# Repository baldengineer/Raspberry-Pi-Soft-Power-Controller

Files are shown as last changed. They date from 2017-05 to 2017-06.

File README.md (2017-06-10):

# Raspberry-Pi-Soft-Power-Controller

For now, you can find more information at:
https://hackaday.io/project/21625-raspberry-pi-soft-power-controller

## Requirements
* Raspberry Pi running Jessie
* 2 GPIO Pins on Raspberry Pi
* AVR (Arduino Uno, Leonardo, etc) w/ 2 GPIO
* Slide Switch (or Pushbutton)

### Optional
* Bald Engineer's RetroPie Controller

## Notes
* Currently the AVR code is designed for a SPST switch and not a push button. I'm working on a push button version, but that isn't what I needed in my project. 
* Please don't fab the PCBs as-is. There are design issues for them. I am open to collaboration on a "hat" version of these boards. I have some ideas. (Key, can we mount a barrel jack upside down??)

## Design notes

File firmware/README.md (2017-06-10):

# firmware

There are two pieces to this project. The code that runs on the AVR (power controller) and some code that runs on the Pi itself. The code on the AVR is somewhat generic, so it could probably power Beagle Bone or other Single-Board Computers.

The code for the RaspberryPi is compiled C code, not python. (You could use Python, but I didn't.) It makes use of the wiringPi library. NOOBS Jessie from April 2017 includes a version of that library in the stock install.

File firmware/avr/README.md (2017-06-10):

# AVR Code

The project I developed this controller for is based on a Arduino Leonardo. That board uses a 32u4 AVR chip. The code itself should be compatible with the 328p and 2560 based boards. However, you will need to change up the I/O pins. (I'm using a custom board.)

Commit b4071b1ddd632b1c1035af2f0c8c23c28ab442d6 was a complete re-write of the original code. As of that commit, it is still a bit messy. However, it works. :)

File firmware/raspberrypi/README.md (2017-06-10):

# RaspberryPi Code
There are two types of files in this directory. One is C-based programs. The other is systemd services. You need them all installed. Here's some detailed notes.

## C-Programs
This project doesn't use Python, it uses C. So you'll need to compile the code on your Pi. These utlities require the "[Wiring Pi](http://wiringpi.com/)" library installed. 

### Installing Wiring Pi
My copy of Jessie had Wiring Pi installed. You can tell by running this command:
```
$ gpio -v
```
If you get something back, it is installed. If you'd like the latest version (or you don't have it installed at all) follow these directions on [installing the latest wiringPi](http://wiringpi.com/download-and-install/).

### C-Start.c
This utility runs at startup. It enables a specific GPIO pin as output and sets it HIGH. I'm using GPIO18 (which is pin 1 in WiringPi's numbering convention. See below for details.) It only needs user-level privilege. 

Compile this code and "install" using:
```
$ gcc c-start.c -o c-start -lwiringPi
$ cp c-start /usr/local/bin/
```
### C-Stop.c
This utility runs during shutdown (and reboot.) It enables a specific GPIO pin as output and sets it LOW. I'm using GPIO18 (which is pin 1 in WiringPi's numbering convention. See below for details.) It only needs user-level privilege. 

Compile this code and "install" using:
```
$ gcc c-stop.c -o c-stop -lwiringPi
$ cp c-stop /usr/local/bin/
```

## systemd services
A big difference between "wheezy" and "jessie" is the init process. wheezy uses SystemInitV and jessie uses systemd. I found a *ton* of questions on how to run a script on startup or shutdown on the raspberry Pi. Everything was SystemInitV based, which won't work with the latest versions of Raspbian. (e.g. if you find putting things in /etc/rc.d isn't working, your linux is probably using systemd).

These could probably be combined into the same service, but I didn't try yet. Also, I can't figure out how to get the shutdown signal to work only on shutdown (and not reboot.)

### powercontrol-comms.service
This service will run c-start during boot and c-stop during shutdown. This is the signal our AVR-based power controller is monitoring. To install, put this file into `/etc/systemd/system`. (Note /lib/systemd is meant for *system* files. Not *user* files.) Once copied, do this:

```
$ cd /etc/systemd/system
$ ls powercontrol-coms.service #verify it is there
$ sudo systemctl enable powercontrol-coms.service
# reboot (or install the next one)
```
Make sure you copy `c-start` and `c-stop` to `/usr/local/bin/`.

### shutdown-gpio.service
This service will run c-watch during boot. This program checks once every second whether the power controller has told us to shutdown. To install, put this file into `/etc/systemd/system`. (Note /lib/systemd is meant for *system* files. Not *user* files.) Once copied, do this:

```
$ cd /etc/systemd/system
$ ls shutdown-gpio.service #verify it is there
$ sudo systemctl enable shutdown-gpio.service
# reboot (or install the previous)
```
Make sure you copy `c-start` and `c-stop` to `/usr/local/sbin/` (different from other file).

## Wiring Pi Pin Numbers
WiringPi has it's own numbering convention. So I made this table to be a quick look up for pin numbers. You can also run "gpio readall" on the Pi for a table.
```
Special :    SD SC                   MO MI SK    | ID  
WiringPi: 3v 08 09 07 0v 00 02 03 3v 12 13 14 0v | 00 05 06 13 19 26 0v
Physical: 01 03 05 07 09 11 13 15 17 19 21 23 25 | 27 29 31 33 35 37 39

Special :          TX RX                   C0 C1 | IC
WiringPi: 5v 5v 0v 15 16 01 0v 04 05 0v 06 10 11 | 01 0v 12 0v 16 20 21
Physical: 02 04 06 08 10 12 14 16 18 20 22 24 26 | 28 30 32 34 36 38 40
```

Special are special functions, so you probably don't want to use those for the power controller. Physical are the actual pin numbers. And then WiringPi is the number to use in the C-code to correspond with the Physical pin number. (It's confusing, but that's why I made the chart.)

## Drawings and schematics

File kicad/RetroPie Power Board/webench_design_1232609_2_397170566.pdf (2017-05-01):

## WEBENCH ® Design Report

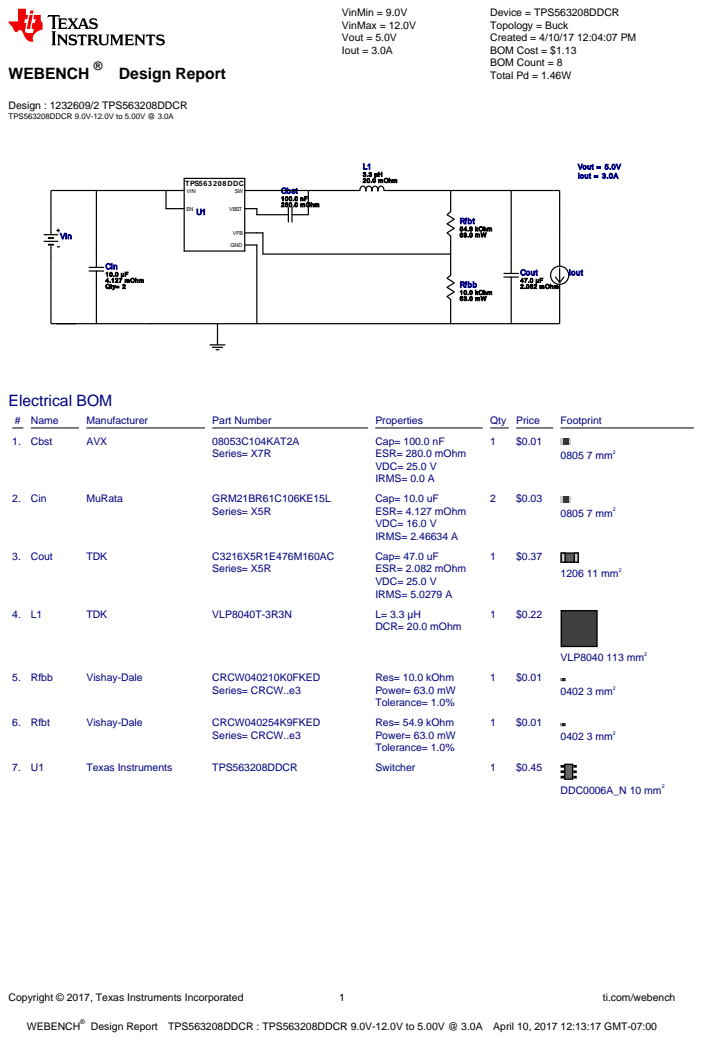
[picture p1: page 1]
Copyright © 2017, Texas Instruments Incorporated; ti.com/webench; WEBENCH®; Design : 1232609/2 TPS563208DDCR TPS563208DDCR 9.0V-12.0V to 5.00V @ 3.0A; VinMin = 9.0V VinMax = 12.0V Vout = 5.0V Iout = 3.0A; Device = TPS563208DDCR Topology = Buck Created = 4/10/17 12:04:07 PM BOM Cost = $1.13 BOM Count = 8 Total Pd = 1.46W; Cbst 100.0 nF 280.0 mOhm; Cin 10.0 µF 4.127 mOhm Qty= 2; Cout 47.0 µF 2.082 mOhm; L1 3.3 µH 20.0 mOhm; Rfbb 10.0 kOhm 63.0 mW; TPS563208DDC; GND; VIN; VFB; VBST U1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

Design Report TPS563208DDCR : TPS563208DDCR 9.0V-12.0V to 5.00V @ 3.0A April 10, 2017 12:13:17 GMT-07:00

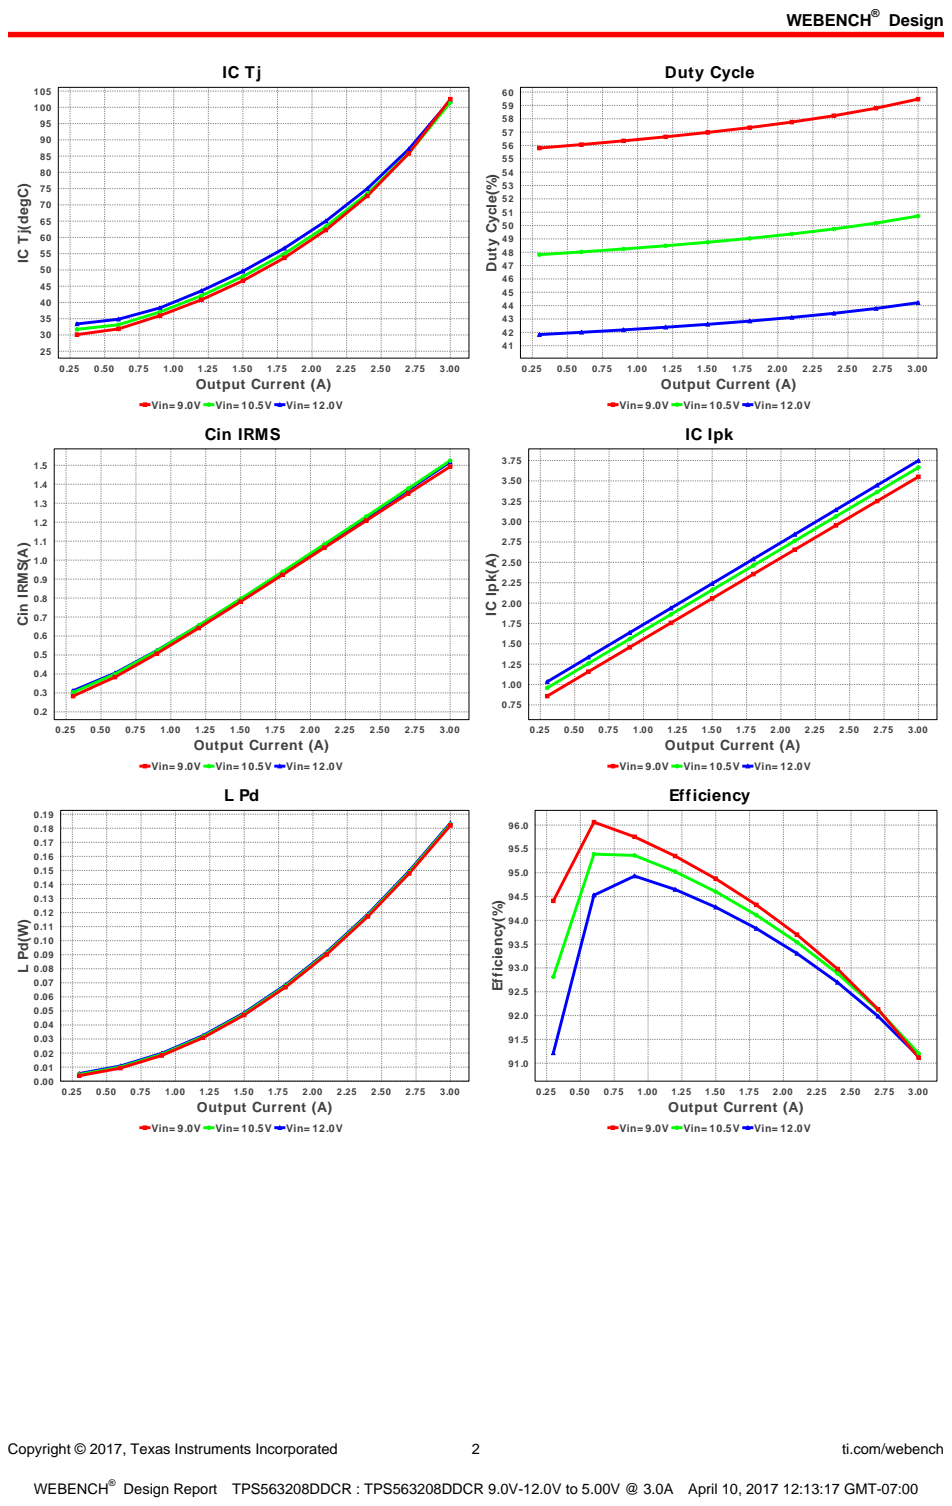
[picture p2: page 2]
Design; Copyright © 2017, Texas Instruments Incorporated; ti.com/webench; 3.00 Output Current (A); Duty Cycle; Duty Cycle(%); Cin IRMS(A); IC Ipk; IC Ipk(A); Efficiency(%)

IC Tj(degC)

Vin= 9.0V Vin= 10.5V Vin= 12.0V
Cin IRMS

Efficiency

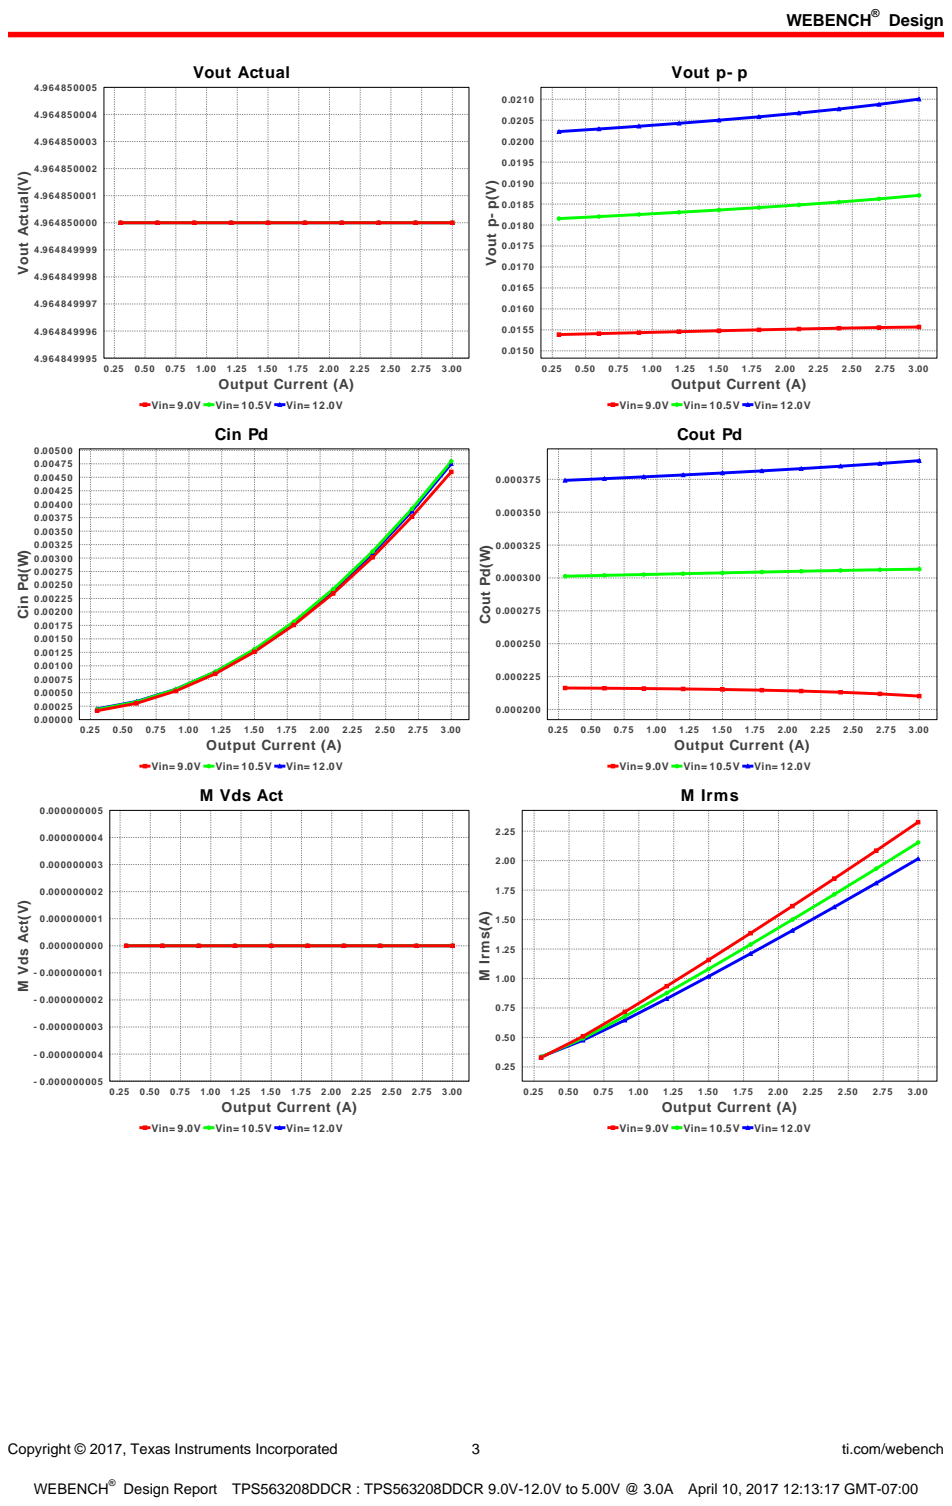
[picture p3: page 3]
Copyright © 2017, Texas Instruments Incorporated; ti.com/webench; Vout Actual; 0.25 0.50 0.75 1.00 1.25 1.50 1.75 2.00 2.25 2.50 2.75 3.00 Output Current (A); Vout Actual(V); Vout p- p; 3.00 Output Current (A); Vout p- p(V); Cin Pd; Cin Pd(W); Cout Pd(W); M Vds Act(V); M Irms; M Irms(A)

Vin= 9.0V Vin= 10.5V Vin= 12.0V

Cout Pd

M Vds Act

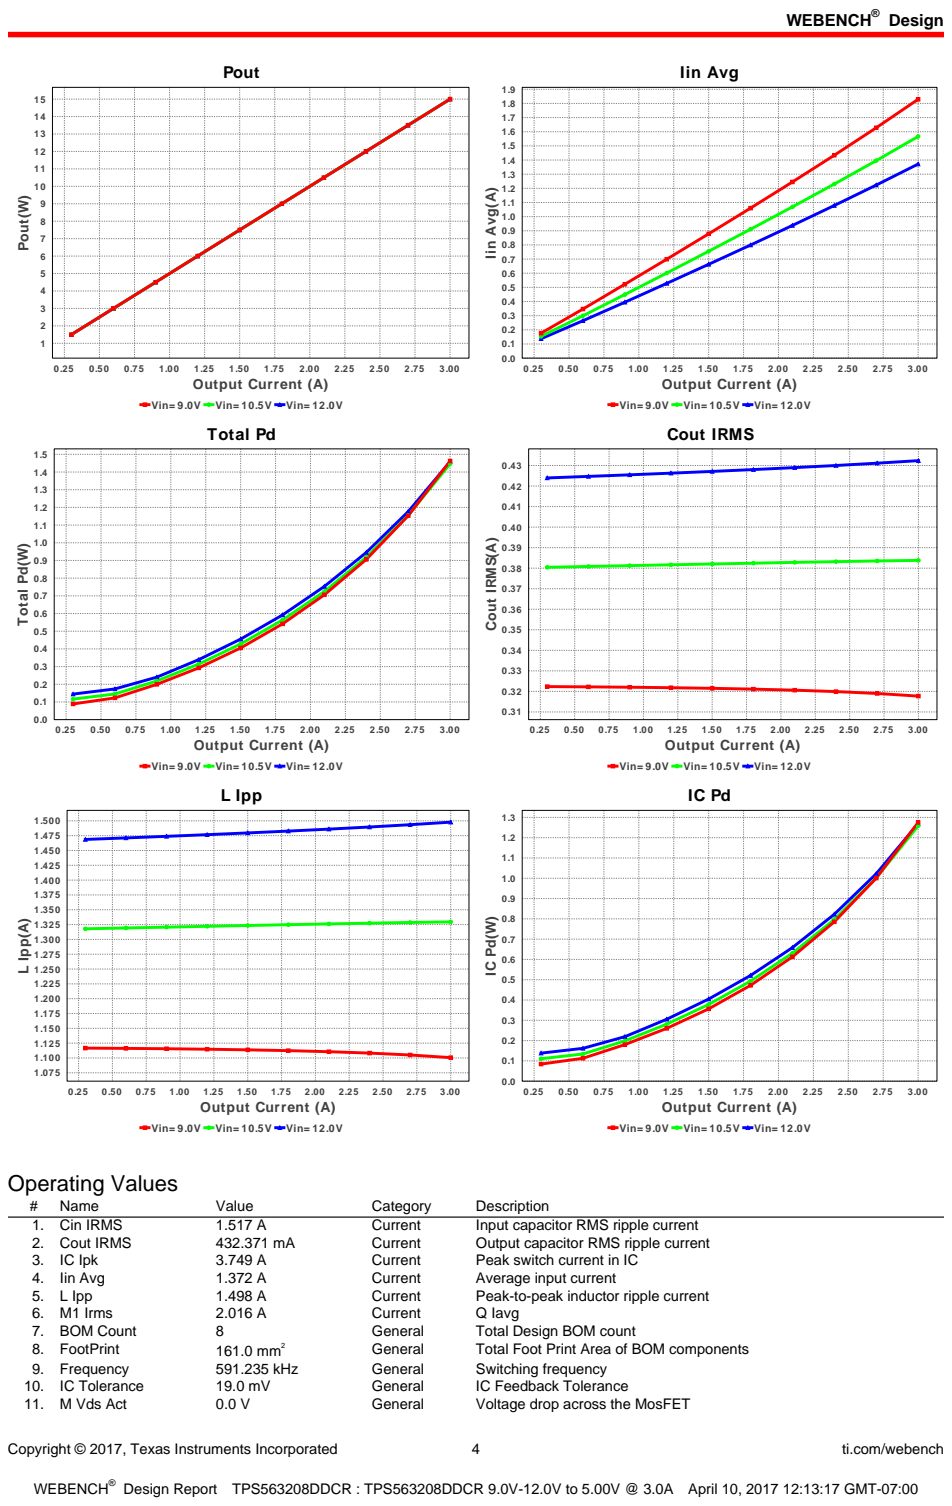
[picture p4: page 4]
Copyright © 2017, Texas Instruments Incorporated; ti.com/webench; Pout; 3.00 Output Current (A); Pout(W); Iin Avg; Iin Avg(A); Total Pd(W); Cout IRMS(A); L Ipp; L Ipp(A); Operating Values; Name; Value; Category; Description; 1. Cin IRMS; Current; Input capacitor RMS ripple current; 2. Cout IRMS; Output capacitor RMS ripple current; 3. IC Ipk; Peak switch current in IC; 4. Iin Avg; Average input current; 5. L Ipp; Peak-to-peak inductor ripple current; 6. M1 Irms; Q Iavg; 7. BOM Count; General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

Vin= 9.0V Vin= 10.5V Vin= 12.0V
Total Pd

Cout IRMS

Copyright © 2017, Texas Instruments Incorporated | 5 | ti.com/webench
# | Name | Value | Category | Description

12. Mode | CCM | General | Conduction Mode
13. Pout | 15.0 W | General | Total output power
14. Total BOM | $1.13 | General | Total BOM Cost
15. Vout Actual | 4.965 V | Op_Point | Vout Actual calculated based on selected voltage divider resistors
16. Vout OP | 5.0 V | Op_Point | Operational Output Voltage
17. Duty Cycle | 44.22 % | Op_point | Duty cycle
18. Efficiency | 91.139 % | Op_point | Steady state efficiency
19. IC Tj | 102.159 degC | Op_point | IC junction temperature
20. ICThetaJA | 60.8 degC/W | Op_point | IC junction-to-ambient thermal resistance
21. IOUT_OP | 3.0 A | Op_point | Iout operating point
22. VIN_OP | 12.0 V | Op_point | Vin operating point
23. Vout p-p | 21.003 mV | Op_point | Peak-to-peak output ripple voltage
24. Cin Pd | 4.751 mW | Power | Input capacitor power dissipation
25. Cout Pd | 389.218 µW | Power | Output capacitor power dissipation
26. IC Pd | 1.269 W | Power | IC power dissipation
27. L Pd | 183.739 mW | Power | Inductor power dissipation
28. Total Pd | 1.458 W | Power | Total Power Dissipation
29. Vout Tolerance | 4.235 % | Vout Tolerance based on IC Tolerance (no load) and voltage divider
| | | | resistors if applicable

## Design Inputs

# | Name | Value | Description

1. Iout | 3.0 | Maximum Output Current
2. VinMax | 12.0 | Maximum input voltage
3. VinMin | 9.0 | Minimum input voltage
4. Vout | 5.0 | Output Voltage
5. base_pn | TPS563208 | Base Product Number
6. source | DC | Input Source Type
7. Ta | 25.0 | Ambient temperature

## Design Assistance
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

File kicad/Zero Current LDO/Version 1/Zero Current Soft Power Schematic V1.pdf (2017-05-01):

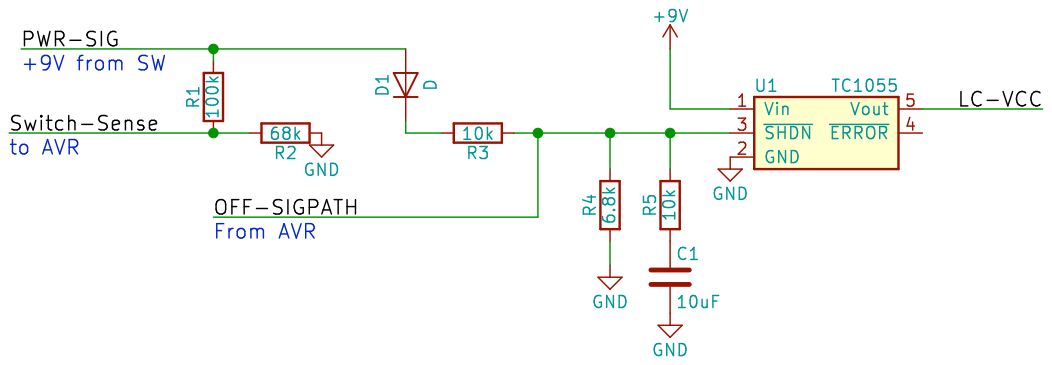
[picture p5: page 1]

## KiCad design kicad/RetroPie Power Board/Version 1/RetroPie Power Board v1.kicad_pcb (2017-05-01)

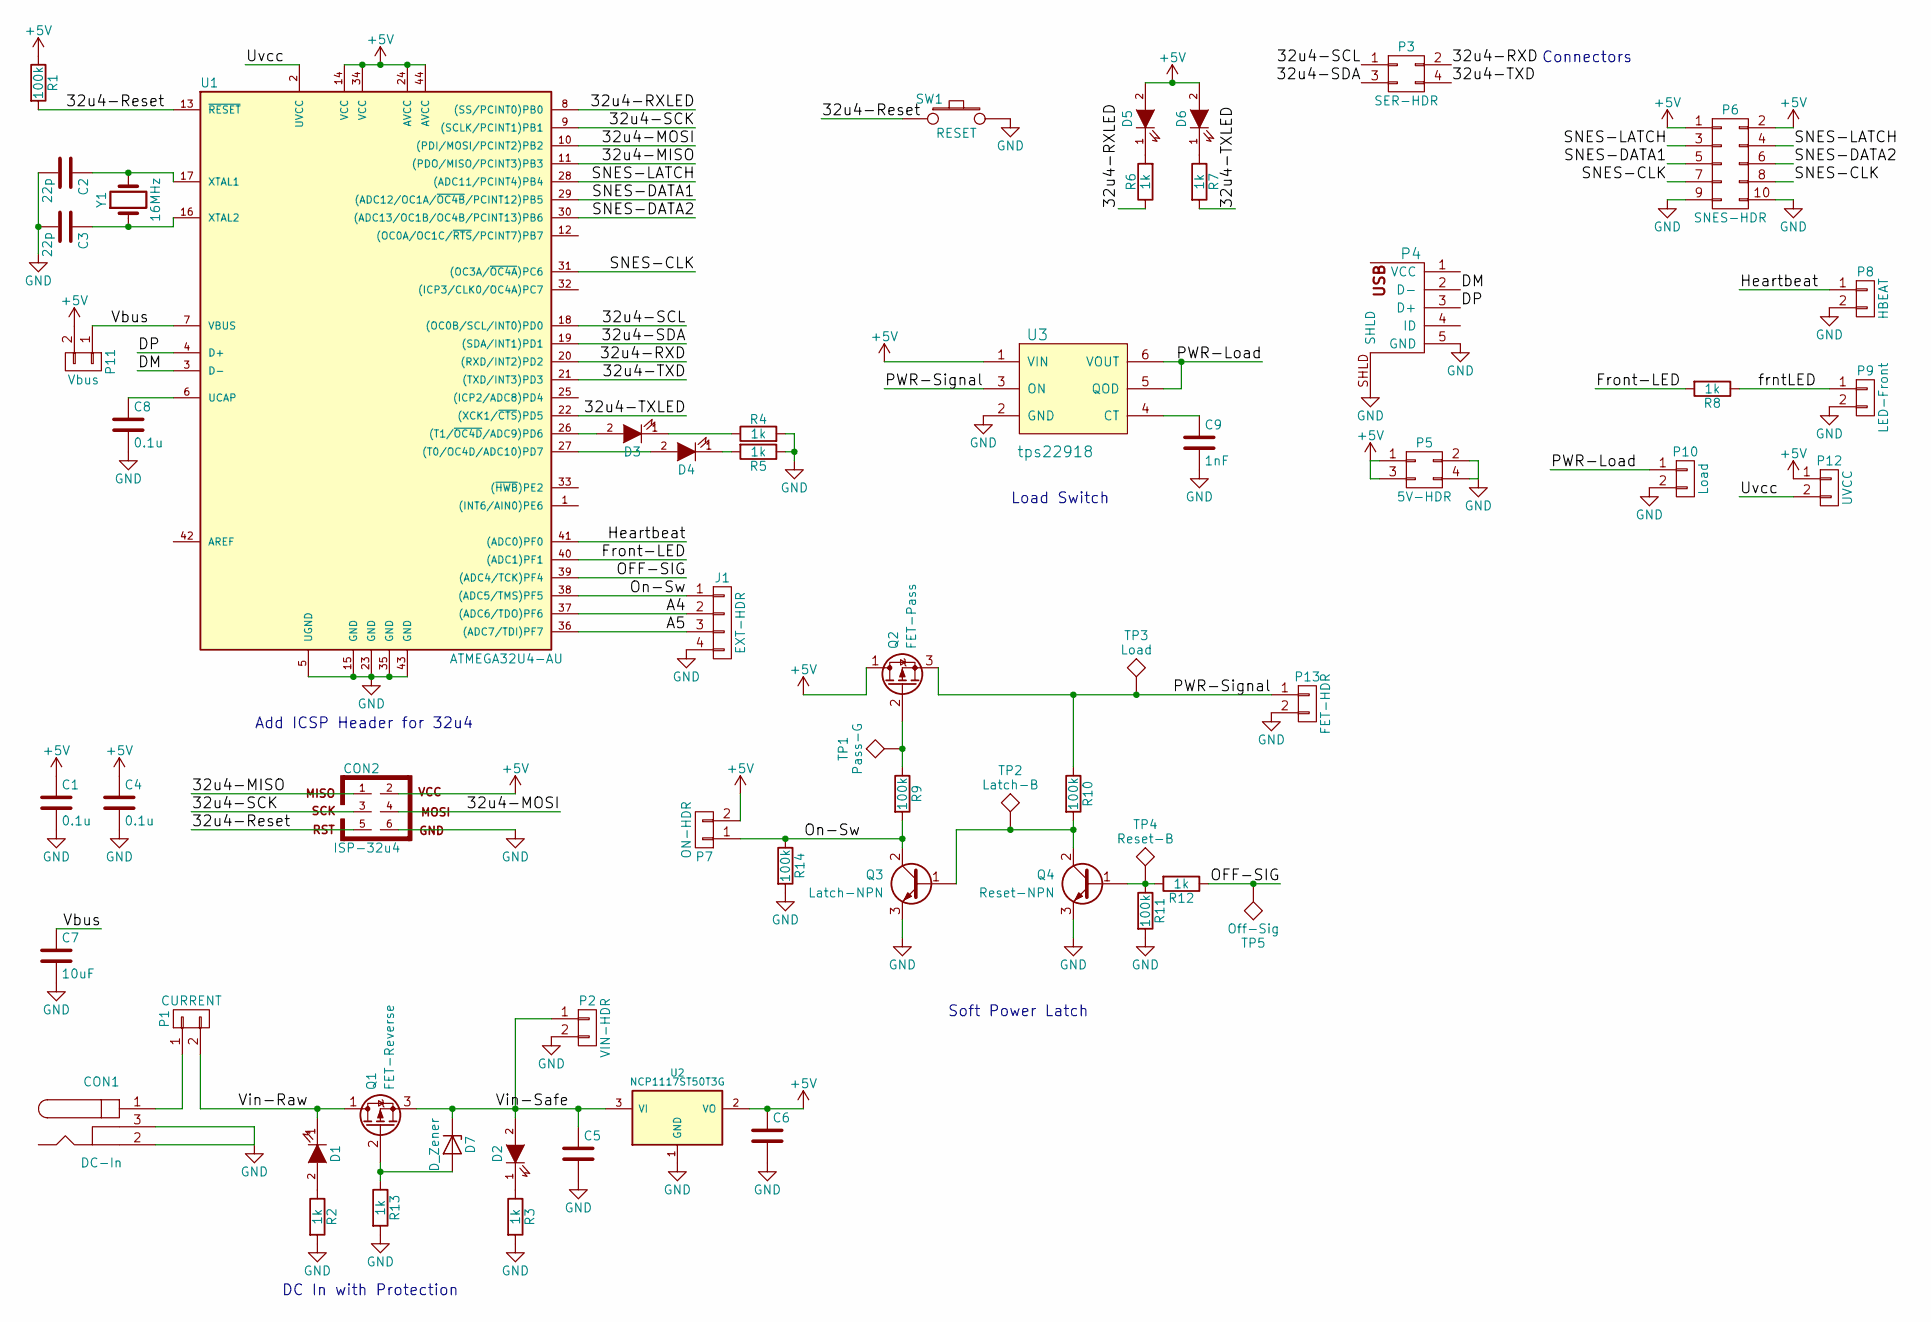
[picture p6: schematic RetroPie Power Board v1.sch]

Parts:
C1, C4: 0.1u; C_1206
C2, C3: 22p; C_1206
C5: CAP 47uF Polymer 10V; c_elec_5x5.3; Mouser PN 710-875105242006
C6: CAP 10uF Polymer 16V; c_elec_5x5.3; Mouser PN 710-875105359001
C7: 10uF; C_1206
C8: 0.1u; C_1206; Mouser PN 80-C1206C106K9PACTM
C9: 1nF; C_1206
CON1: DC-In; POWER_JACK_PTH
CON2: ISP-32u4; 2X03
D1: REV-RED; LED-1206
D2: GRN-PWRGD; LED-1206
D3: 32u4-LED1; LED-1206
D4: 32u4-LED2; LED-1206
D5: RXLED; LED-1206
D6: TXLED; LED-1206
D7: D_Zener; SOD-323_HandSoldering; Mouser PN 755-TFZVTR12B
J1: EXT-HDR; 1X04
P1: CURRENT; Pin_Header_Straight_1x02
P2: VIN-HDR; Pin_Header_Straight_1x02
P3: SER-HDR; Pin_Header_Straight_2x02
P4: USB_5PIN_SHELL; USB-MICRO_TH_4PEGS
P5: 5V-HDR; Pin_Header_Straight_2x02
P6: SNES-HDR; Pin_Header_Straight_2x05
P7: ON-HDR; Pin_Header_Straight_1x02
P8: HBEAT; Pin_Header_Straight_1x02
P9: LED-Front; Pin_Header_Straight_1x02
P10: Load; Pin_Header_Straight_1x02
P11: Vbus; Pin_Header_Straight_1x02
P12: UVCC; Pin_Header_Straight_1x02
P13: FET-HDR; Pin_Header_Straight_1x02
Q1: FET-Reverse; SOT-323; Mouser PN 863-MCH3383-TL-H
Q2: FET-Pass; SOT-323; Mouser PN 863-MCH3383-TL-H
Q3: Latch-NPN; SOT-23; Mouser PN 863-MMBT2222ALT1G
Q4: Reset-NPN; SOT-23; Mouser PN 863-MMBT2222ALT1G
R1, R9, R10, R11, R14: 100k; R_1206
R2, R3, R4, R5, R6, R7, R8, R12, R13: 1k; R_1206
SW1: RESET; SW_PUSHBUTTON_SMD
TP1: Pass-G; SolderWirePad_single_1-5mmDrill
TP2: Latch-B; SolderWirePad_single_1-5mmDrill
TP3: Load; SolderWirePad_single_1-5mmDrill
TP4: Reset-B; SolderWirePad_single_1-5mmDrill
TP5: Off-Sig; SolderWirePad_single_1-5mmDrill
U1: ATMEGA32U4-AU; QFP80P1200X1200X120-44N
U2: NCP1117ST50T3G; SOT223
U3: tps22918; SOT23-6
Y1: 16MHz; CRYSTAL_HC49_SMD

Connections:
+5V: C1.1, C4.1, C6.1, CON2.2, D5.2 (A), D6.2 (A), P5.1, P5.3, P6.1, P6.2, P7.2, P11.2, P12.1, Q2.1 (D), R1.1, U1.14 (VCC), U1.24 (AVCC), U1.34 (VCC), U1.44 (AVCC), U2.2 (VO), U3.1 (VIN)
/32u4-MISO: CON2.1, U1.11 ((PDO/MISO/PCINT3)PB3)
/32u4-MOSI: CON2.4, U1.10 ((PDI/MOSI/PCINT2)PB2)
/32u4-RXD: P3.2, U1.20 ((RXD/INT2)PD2)
/32u4-RXLED: R6.1, U1.8 ((SS/PCINT0)PB0)
/32u4-Reset: CON2.5, R1.2, SW1.1, U1.13 (~RESET~)
/32u4-SCK: CON2.3, U1.9 ((SCLK/PCINT1)PB1)
/32u4-SCL: P3.1, U1.18 ((OC0B/SCL/INT0)PD0)
/32u4-SDA: P3.3, U1.19 ((SDA/INT1)PD1)
/32u4-TXD: P3.4, U1.21 ((TXD/INT3)PD3)
/32u4-TXLED: R7.2, U1.22 ((XCK1/~CTS~)PD5)
/A4: J1.2, U1.37 ((ADC6/TDO)PF6)
/A5: J1.3, U1.36 ((ADC7/TDI)PF7)
/DM: P4.2 (D-), U1.3 (D-)
/DP: P4.3 (D+), U1.4 (D+)
/Front-LED: R8.2, U1.40 ((ADC1)PF1)
/Heartbeat: P8.1, U1.41 ((ADC0)PF0)
/OFF-SIG: R12.1, TP5.1, U1.39 ((ADC4/TCK)PF4)
/On-Sw: J1.1, P7.1, Q3.2 (C), R9.2, R14.1, U1.38 ((ADC5/TMS)PF5)
/PWR-Load: P10.1, U3.5 (QOD), U3.6 (VOUT)
/PWR-Signal: P13.1, Q2.3 (S), R10.1, TP3.1, U3.3 (ON)
/SNES-CLK: P6.7, P6.8, U1.31 ((OC3A/~OC4A~)PC6)
/SNES-DATA1: P6.5, U1.29 ((ADC12/OC1A/~OC4B~/PCINT12)PB5)
/SNES-DATA2: P6.6, U1.30 ((ADC13/OC1B/OC4B/PCINT13)PB6)
/SNES-LATCH: P6.3, P6.4, U1.28 ((ADC11/PCINT4)PB4)
/Uvcc: P12.2, U1.2 (UVCC)
/Vbus: C7.1, P11.1, U1.7 (VBUS)
/Vin-Raw: D1.1 (K), P1.2, Q1.1 (D)
/Vin-Safe: C5.1, D2.2 (A), D7.1 (K), P2.1, Q1.3 (S), U2.3 (VI)
/frntLED: P9.1, R8.1
GND: C1.2, C2.2, C3.2, C4.2, C5.2, C6.2, C7.2, C8.2, C9.2, CON1.2, CON1.3, CON2.6, J1.4, P2.2, P4.5 (GND), P4.SHLD, P5.2, P5.4, P6.9, P6.10, P8.2, P9.2, P10.2, P13.2, Q3.3 (E), Q4.3 (E), R2.2, R3.2, R4.2, R5.1, R11.2, R13.2, R14.2, SW1.2, U1.5 (UGND), U1.15 (GND), U1.23 (GND), U1.35 (GND), U1.43 (GND), U2.1 (GND), U3.2 (GND)
unnamed: C2.1, U1.17 (XTAL1), Y1.2
unnamed: C3.1, U1.16 (XTAL2), Y1.1
unnamed: C8.1, U1.6 (UCAP)
unnamed: C9.1, U3.4 (CT)
unnamed: CON1.1, P1.1
unnamed: D1.2 (A), R2.1
unnamed: D2.1 (K), R3.1
unnamed: D3.1 (K), R4.1
unnamed: D3.2 (A), U1.26 ((T1/~OC4D~/ADC9)PD6)
unnamed: D4.1 (K), R5.2
unnamed: D4.2 (A), U1.27 ((T0/OC4D/ADC10)PD7)
unnamed: D5.1 (K), R6.2
unnamed: D6.1 (K), R7.1
unnamed: D7.2 (A), Q1.2 (G), R13.1
unnamed: Q2.2 (G), R9.1, TP1.1
unnamed: Q3.1 (B), Q4.2 (C), R10.2, TP2.1
unnamed: Q4.1 (B), R11.1, R12.2, TP4.1

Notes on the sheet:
Soft Power Latch
Add ICSP Header for 32u4
DC In with Protection
Load Switch
Connectors

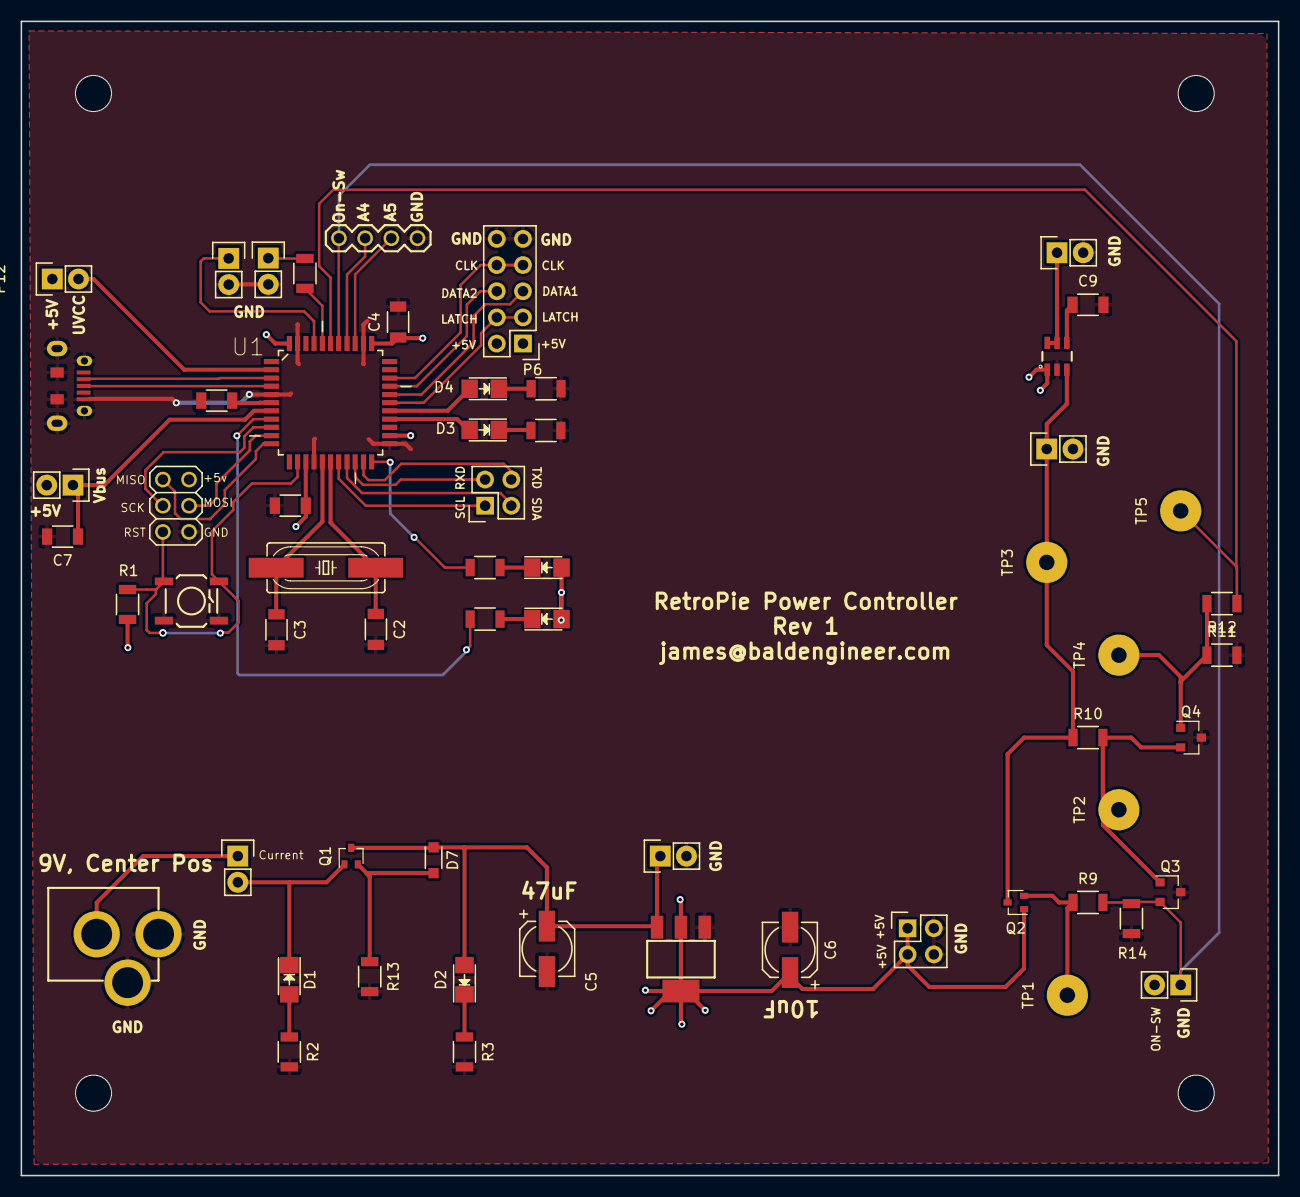
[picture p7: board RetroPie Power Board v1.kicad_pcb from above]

Board: 2 copper layers, 122.0 x 112.0 mm, 60 parts (0 on the bottom side), 48 nets.

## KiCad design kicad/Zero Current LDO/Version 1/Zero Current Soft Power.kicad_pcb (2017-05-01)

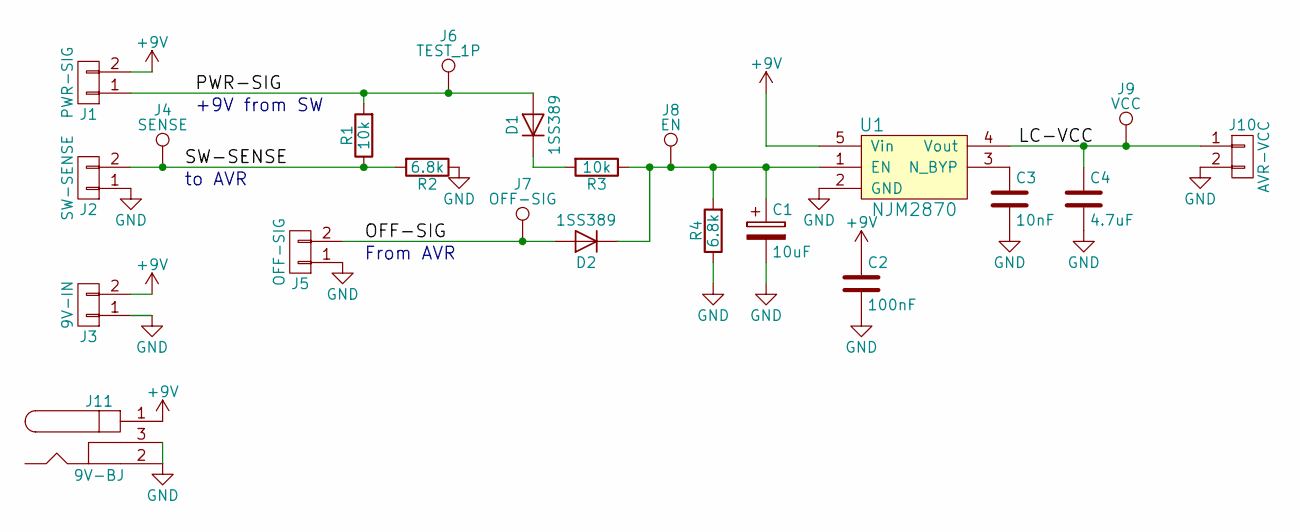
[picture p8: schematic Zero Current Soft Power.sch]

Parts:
C1: 10uF; c_elec_5x5.3; Mouser-PN 710-875105359001
C2: 100nF; C_1206_HandSoldering
C3: 10nF; C_1206_HandSoldering
C4: 4.7uF; C_1206_HandSoldering
D1, D2: 1SS389; SOD-523; Mouser-PN 757-1SS389L3F
J1: PWR-SIG; Pin_Header_Straight_1x02
J2: SW-SENSE; Pin_Header_Straight_1x02
J3: 9V-IN; Pin_Header_Straight_1x02
J4: SENSE; SolderWirePad_single_2mmDrill
J5: OFF-SIG; Pin_Header_Straight_1x02
J6: TEST_1P; SolderWirePad_single_2mmDrill
J7: OFF-SIG; SolderWirePad_single_2mmDrill
J8: EN; SolderWirePad_single_2mmDrill
J9: VCC; SolderWirePad_single_2mmDrill
J10: AVR-VCC; Pin_Header_Straight_1x02
J11: 9V-BJ; POWER_JACK_PTH
R1, R3: 10k; R_1206_HandSoldering
R2: 6.8k; R_1206_HandSoldering
R4: 6.8k; C_1206_HandSoldering
U1: NJM2870; SOT-23-5; Mouser-PN NJM2870F05-TE2

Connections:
+9V: C2.1, J1.2, J3.2, J11.1, U1.5 (Vin)
/LC-VCC: C4.1, J9.1, J10.1, U1.4 (Vout)
/OFF-SIG: D2.2 (A), J5.2, J7.1
/PWR-SIG: D1.2 (A), J1.1, J6.1, R1.2
/SW-SENSE: J2.2, J4.1, R1.1, R2.2
GND: C1.2, C2.2, C3.2, C4.2, J2.1, J3.1, J5.1, J10.2, J11.2, J11.3, R2.1, R4.1, U1.2 (GND)
unnamed: C1.1, D2.1 (K), J8.1, R3.1, R4.2, U1.1 (EN)
unnamed: C3.1, U1.3 (N_BYP)
unnamed: D1.1 (K), R3.2

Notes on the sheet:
From AVR
+9V from SW
to AVR

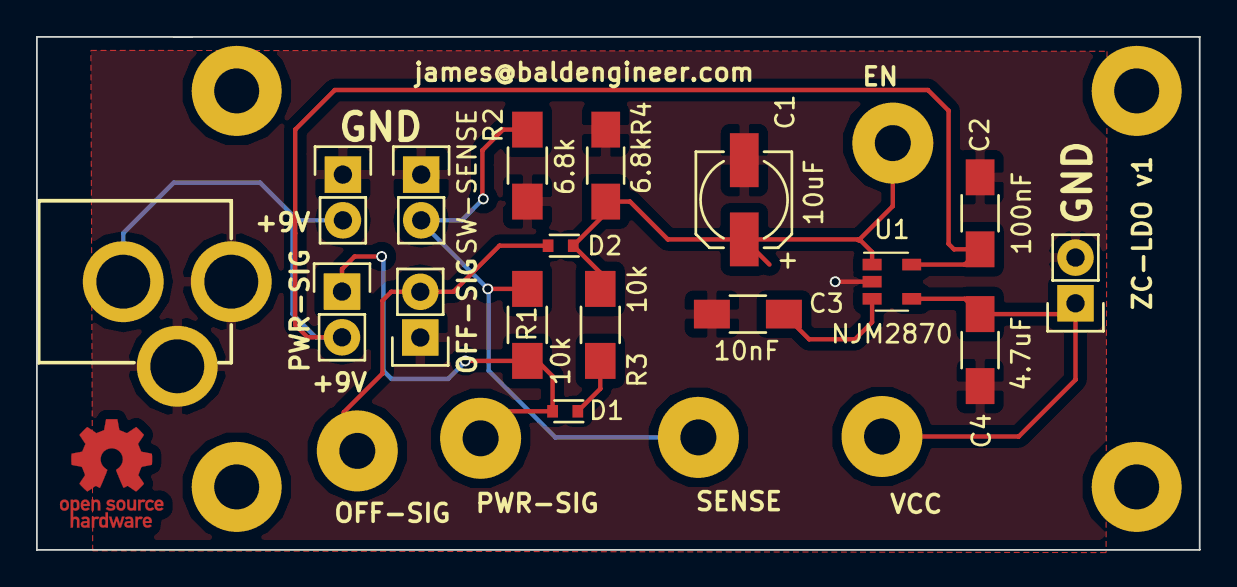
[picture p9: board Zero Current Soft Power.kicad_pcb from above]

Board: 2 copper layers, 64.6 x 28.5 mm, 22 parts (0 on the bottom side), 9 nets.

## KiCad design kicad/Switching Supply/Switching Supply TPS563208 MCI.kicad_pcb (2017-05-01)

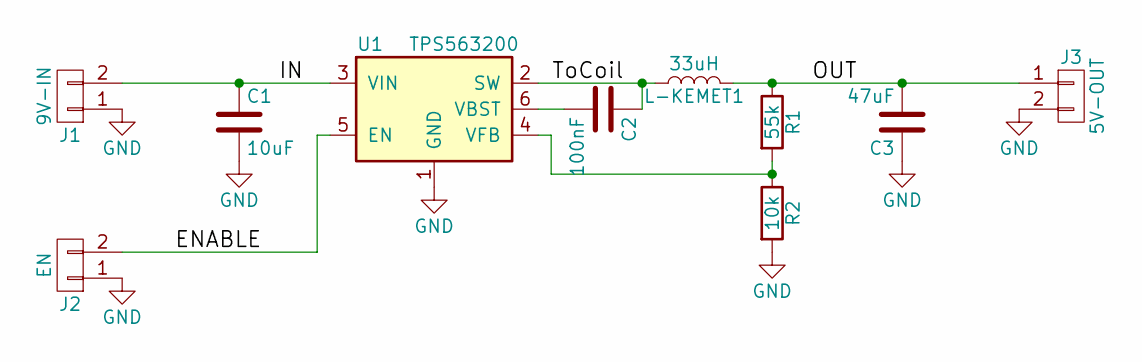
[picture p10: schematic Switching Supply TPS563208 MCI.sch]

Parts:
C1: 10uF; C_0805_HandSoldering
C2: 100nF; C_0805_HandSoldering
C3: 47uF; C_1206_HandSoldering
J1: 9V-IN; 1X02
J2: EN; 1X02
J3: 5V-OUT; 1X02
L-KEMET1: 33uH; KT-MPLCH-0740-Hand
R1: 55k; R_0402
R2: 10k; R_0402
U1: TPS563200; SOT-23-6; Mouser-PN 595-TPS563208DDCT

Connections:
/ENABLE: J2.2, U1.5 (EN)
/IN: C1.1, J1.2, U1.3 (VIN)
/OUT: C3.2, J3.1, L-KEMET1.2, R1.1
/ToCoil: C2.1, L-KEMET1.1, U1.2 (SW)
GND: C1.2, C3.1, J1.1, J2.1, J3.2, R2.2, U1.1 (GND)
unnamed: C2.2, U1.6 (VBST)
unnamed: R1.2, R2.1, U1.4 (VFB)

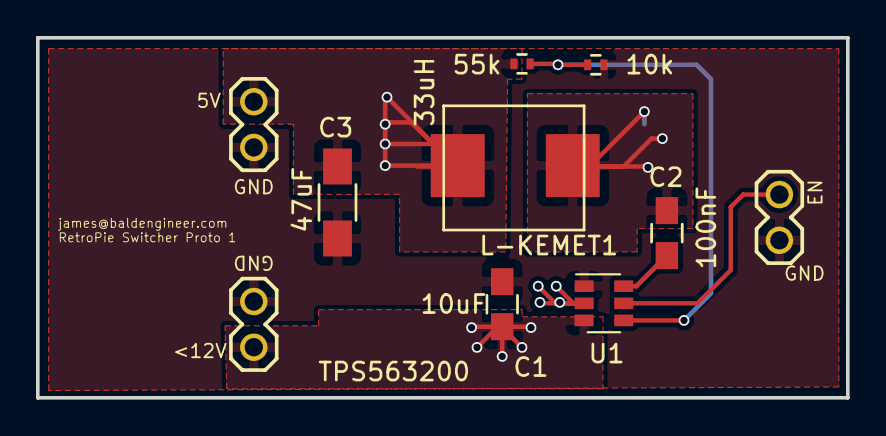
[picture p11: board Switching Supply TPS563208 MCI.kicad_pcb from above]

Board: 2 copper layers, 45.0 x 20.0 mm, 10 parts (0 on the bottom side), 7 nets.

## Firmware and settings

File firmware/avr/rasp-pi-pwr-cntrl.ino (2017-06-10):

//retropie-pwr-cntrl-v4.ino
// This code expects a SPST slide switch
// For more information, visit baldengineer.com and search "SNES"
// Code is still a work in progress

const byte signalFromPi = 3;  //PD0 is SCL
//const byte switchSense = 7;
const byte switchSense = A2;    //PF5
const byte offSignalPath = A3; //PF4 Verify: no additional Z, adc 4 on 32u4
const byte heartBeatLED = 6;  
const byte debugLED = 12;
const byte frontLED = A4;       // PF1 
const byte signalToPi = A5;// PF0 (is HeartBeat on Pi)
const byte extraA1 = A1;  // PF6, Mine: A4 - Actually A1
//const byte extraA0 = A0;  // PF7, Mine: A5 - Actually A0
const byte loadEnable = A1; // The Pi!
const byte switchLED = A0; // PD6

#define enableON HIGH
#define enableOFF LOW

unsigned long previousOFFSignalCount = millis();
unsigned long previousOFFSignalInterval = 1000;

unsigned long heartBeatPreviousMillis = millis();
unsigned long heartBeatInterval = 500;
bool heartBeatState = true;

unsigned long timerOffPreviousMillis = millis();
unsigned long timerOffInterval = 15000; 

unsigned long capDrainPreviousMillis = millis();
unsigned long capDrainInterval = 1000; 

unsigned long forcePowerOff = millis();
unsigned long forcePowerOffInterval = 45000UL; 
bool forcePowerOffState = false;

bool currentButtonState;
bool previousButtonState;

bool currentPiSignalState;
bool previousPiSignalState;

enum controllerStates {
	POWER_UP,
	BOOTING_PI,
	BOOTED,
	SHUT_DOWN_PI,
	POWER_DOWN
};
enum controllerStates controllerState = POWER_UP;
enum controllerStates previousControllerState = controllerState;

/*enum piPowerStates {
	OFF,
	BOOTING,
	BOOTED,
	SHUTTING_DOWN,
	KILLED
};
enum piPowerStates piPowerState = OFF;
enum piPowerStates previousPiPowerState = OFF; */

/*enum pwrButtonStates {
	UNKNOWN,
	SW_OFF,
	SW_ON,
	CHANGED
};
enum pwrButtonStates pwrButtonState = UNKNOWN;
enum pwrButtonStates previousPwrButtonState = UNKNOWN;*/


void setup() {
	Serial.begin(9600);	// debugging 
	pinMode(debugLED, OUTPUT);

	pinMode(offSignalPath, INPUT);

	pinMode(heartBeatLED, OUTPUT);
	pinMode(switchSense, INPUT);
	pinMode(signalFromPi, INPUT);

	pinMode(signalToPi, OUTPUT);
	digitalWrite(signalToPi, LOW);
	
	pinMode(loadEnable, OUTPUT);
	digitalWrite(loadEnable, enableOFF);
}

void heartBeat(unsigned long millisTime) {
	if (millisTime - heartBeatPreviousMillis >= heartBeatInterval) {
		heartBeatPreviousMillis = millisTime;	
		heartBeatState = !heartBeatState;
		digitalWrite(heartBeatLED, heartBeatState);
	}
}


void stateDebug() {
	if (previousControllerState != controllerState) {
		Serial.println(controllerState);
		previousControllerState = controllerState;
	}
}

/*int processPiSignalChange(bool piState) {
	// save it, for some reason
	previousPiPowerState = piPowerState;
	if (piState)
		return BOOTED;
	else
		return SHUTTING_DOWN;
}

int processPwrButtonChange(bool buttonState) {
	pwrButtonState = previousPwrButtonState;
	if (buttonState)
		return CHANGED_TO_ON;
	else
		return CHANGED_TO_OFF;
}*/

void loop() {
	// blink the LED
	heartBeat(millis());

	// check where the Pi is at
	currentPiSignalState = digitalRead(signalFromPi);
	if (previousPiSignalState != currentPiSignalState) {
		// in case has some noise wait and re-sample
		delay(10);
		currentPiSignalState = digitalRead(signalFromPi);
		previousPiSignalState = currentPiSignalState;

		//piPowerState = processPiSignalChange(currentPiSignalState);
	} 

	// how is the button doing?
	currentButtonState = digitalRead(switchSense);
	if (previousButtonState != currentButtonState) {
		// in case of bounce, wait and re-sample
		delay(20);
		currentButtonState = digitalRead(switchSense);
		previousButtonState = currentButtonState;

		// let the Pi know if it should be on or off
		digitalWrite(signalToPi, currentButtonState);

		if (currentButtonState == LOW) {
			// user is forcing shutdown, so start emergency timer
			//timerOffPreviousMillis = millis(); 
			pinMode(offSignalPath, OUTPUT);
			digitalWrite(offSignalPath, HIGH);
			forcePowerOff = millis();
		}

		//pwrButtonState = processPwrButtonChange(currentButtonState);
		//pwrButtonState = CHANGED;
	}

	switch (controllerState) {
		case POWER_UP:
			stateDebug();
			// disable heart beat 
			heartBeatPreviousMillis = millis();
			heartBeatState = false;

			// should be a no brainer.
			if (currentButtonState) {
				//pwrButtonState = SW_ON;
				controllerState = BOOTING_PI;
			}	
		break;

		case BOOTING_PI:
			//stateDebug();
			heartBeatInterval = 1000;

			// Turn on the Pi
			digitalWrite(loadEnable, enableON);

			// wait for Pi to boot
			if (currentPiSignalState) {
				controllerState = BOOTED;
			}

			// kill the power if the Pi never boot (or we never)
			// get our PiAlive signal.
			if (currentButtonState == LOW) {
				capDrainPreviousMillis = millis();
				digitalWrite(signalToPi, LOW);
				controllerState = POWER_DOWN;
			}
		break;

		case BOOTED:
			//stateDebug();
			heartBeatInterval = 500;

			// wait for Pi signal that it is shutting down
			if (currentPiSignalState == LOW) {
				// Pi Initiated Shutdown
				timerOffPreviousMillis = millis();
				controllerState = SHUT_DOWN_PI;
			}

			if (currentButtonState == LOW) {
				// User is telling Pi to shut down.
				timerOffPreviousMillis = millis(); // moved to switch change
				//forcePowerOff = millis();
				controllerState = SHUT_DOWN_PI;
			} else {
				// let the swtich keep the cap up.
				pinMode(offSignalPath, INPUT);
			}


		break;

		case SHUT_DOWN_PI:
			//stateDebug();
			heartBeatInterval = 250;
			// give the Pi some time to finish up its power-down
			if (currentPiSignalState == LOW) {
				if (millis() - timerOffPreviousMillis >= timerOffInterval) {
					controllerState = POWER_DOWN;
					capDrainPreviousMillis = millis();
				}
			}

			// or a reboot is occured
			if (currentPiSignalState) {
				controllerState = BOOTED;
			}

			// Shutdown took way too long
			if (millis() - forcePowerOff >= forcePowerOffInterval) {
				controllerState = POWER_DOWN;
				capDrainPreviousMillis = millis();
			}
		break;

		case POWER_DOWN:
			//stateDebug();
			heartBeatInterval = 100;

			// let the cap drain once the switch goes off.
			if (currentButtonState == LOW) {
				// turn off the Pi
				digitalWrite(loadEnable, enableOFF);
				if (millis() - capDrainPreviousMillis >= capDrainInterval) {
					// drain the cap
					pinMode(offSignalPath, OUTPUT);
					digitalWrite(offSignalPath, LOW);
				}				
			}
		break;
	}
}

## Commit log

2017-05-01 first commit, it's probably broken.
    [RetroPie Power Board v1.kicad_pcb, RetroPie Power Board v1.sch, RetroPie Power Board v1a.kicad_pcb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]
2017-05-03 Delete Zero Current Soft Power v2.kicad_pcb
    Really shouldn't have published this yet, since it is just a copy of V1. It doesn't fix any flaws yet.
    [Zero Current Soft Power v2.kicad_pcb]
2017-06-10 Major Update. New State Machine. Fixed systemd
    [c-stop.c, rasp-pi-pwr-cntrl.ino]
